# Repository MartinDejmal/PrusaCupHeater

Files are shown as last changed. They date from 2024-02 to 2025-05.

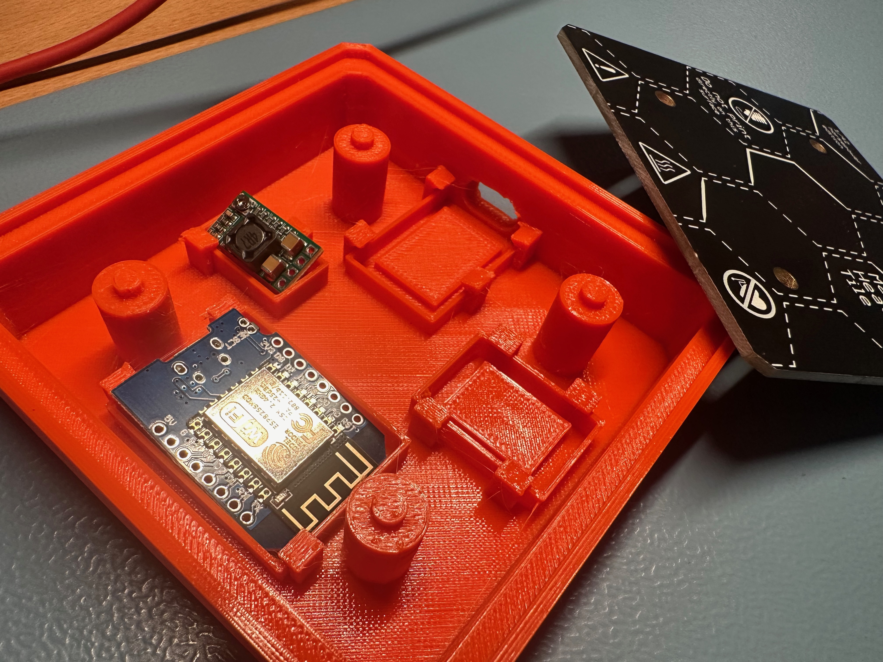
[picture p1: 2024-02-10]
Pictures/IMG_0196.jpeg

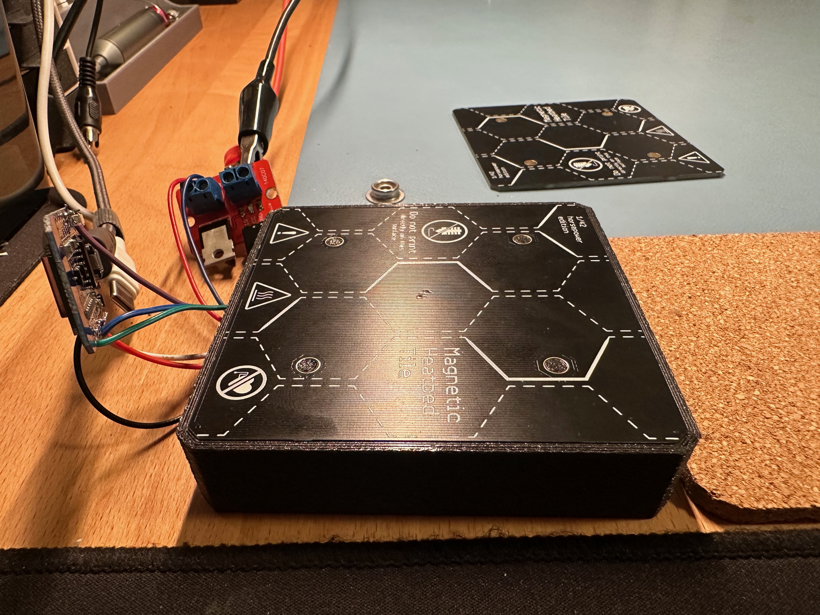
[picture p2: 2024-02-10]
Pictures/IMG_0191.jpeg

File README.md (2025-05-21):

# PrusaCupHeater

PrusaCupHeater is a project aiming to utilize spare / waste heatbedlets (heat bed tiles) from **Prusa XL printer**. 

The ultimate objective was to build a cup heater that can be powered from USB-C PD power supply and connected to Home Assistant. 

Original idea and design by [Martin Velisek](https://x.com/martin_velisek) & [Martin Dejmal](https://x.com/KutilDomaci).

## Required parts

* Prusa XL Heat Bed Tile (obviously)
* Wemos D1 Mini ESP8266 module (or similar)
* DS18B20 temperature sensor (or any alternative)
* power MOSFET/PWM breakout board
* USB-C PD Trigger with 20V out support
* DC-DC step-down converter (at least 24V input, 5V output)
* optional: 3 LED strip WS2812B
* 3D Printed box

### Purchase links

| Component/Module | CZ | International |
| --- | --- | --- |
| Prusa XL Heatbed tile | [prusa3d.com](https://www.prusa3d.com/cs/produkt/heatbed-tile/) ||
| Wemos D1 Mini | [laskakit.cz](https://www.laskakit.cz/wemos-d1-mini-esp8266-wifi-modul/), [pajenicko.cz](https://pajenicko.cz/wemos-d1-mini-wifi-esp8266-esp-12f-microusb) | [Aliexpress](https://www.aliexpress.com/item/1005006473868001.html) |
| DS18B20 temp sensor | [laskakit.cz](https://www.laskakit.cz/dallas-digitalni-cidlo-teploty-ds18b20--to-92/), [pajenicko.cz](https://pajenicko.cz/digitalni-cidlo-teploty-dallas-ds18b20) | [Aliexpress](https://www.aliexpress.com/item/1005006105455874.html) |
| MOSFET module | [laskakit.cz](https://www.laskakit.cz/pwm-mosfet-modul-d4184--40vdc-50a/)|[Aliexpress](https://www.aliexpress.com/item/1005004768394186.html) |
| USB-C PD trigger | [laskakit.cz](https://www.laskakit.cz/laskakit-usb-c-pd-ch224k-prepinac-napajeciho-napeti/) | |
| DC-DC Step-down converter | [laskakit.cz](https://www.laskakit.cz/mikro-step-down-menic--nastavitelny/), [pajenicko.cz](https://pajenicko.cz/miniaturni-menic-napeti-step-down-4-dot-5v-24v-na-0-dot-8v17v-az-3a) | [Aliexpress](https://www.aliexpress.com/item/32807048132.html) |
| WS2812 LED strip (60 LED/m; 3 LEDs total) | [laskakit.cz](https://www.laskakit.cz/led-pasek-neopixel-ws2812b-60led-m-ip65-5m-cerny/), [pajenicko.cz](https://pajenicko.cz/inteligentni-rgb-led-pasek-1m-ws2812-neopixel-60led-m-18w-m) | |

## Assembly instructions
- wire up the modules following way:
  - **DS18B20** to pin D7 on **Wemos D1**, glue the sensor to the bottom of the heat bed tile  
  - power MOSFET module to pin D1 on **Wemos D1**
  - (optional) **WS2812** to pin D6 on **Wemos D1** 
- jumper the USB-C trigger to output 20V
  - wire 20V out from the PD trigger into the MOSFET switching part
  - connect power pins from MOSFET trigger into the heat bed tile

## Firmware instructions
- flash `tasmota-sensors` into the **Wemos D1**, you can use [Tasmota Web Installer](https://tasmota.github.io/install/)
- apply following template:
  - without **WS2812** `{"NAME":"PrusaCupHeater","GPIO":[0,0,0,0,0,224,0,0,0,1312,0,0,0,0],"FLAG":0,"BASE":18}`
  - with **WS2812** `{"NAME":"PrusaCupHeater","GPIO":[0,0,0,0,0,224,0,0,1376,1312,0,0,0,0],"FLAG":0,"BASE":18}`

## Home Assistant configuration
Prerequisite: Tasmota integration working with MQTT server
- if you want to control the Cup Heater via Home Assistant, you need to define a thermostat
- open your configuration.yaml and add following:
```
  climate:
    - platform: generic_thermostat
      unique_id: prusa_cup_heate
      name: PrusaCupHeater
      heater: switch.tasmota_2
      target_sensor: sensor.tasmota_ds18b20_temperature
      min_temp: 40
      max_temp: 120
```
Replace `switch.tasmota_2` and `sensor.tasmota_ds18b20_temperature` by relevant heater switch and temperature sensors entities in your setup. 
- change **Logging interval** on your Tasmota to lowest possible value (10s) - **Configuration -> Configure Logging -> Telemetry Period**

## Standalone operation configuration
It is possible to enable simple heating control using Tasmota Rules. To do this, open **Tasmota Console** and create two rules by entering following commands:
  - `Rule1 ON Tele-DS18B20#Temperature<55 DO Power1 1 ENDON`
  - `Rule2 ON Tele-DS18B20#Temperature>65 DO Power1 0 ENDON`
- enable the rules using following commands:
  - `Rule1 1`
  - `Rule2 1`
- if you have **WS2812** add third rule to light it up when heating is active:
  - `Rule3 ON Power1#State=1 DO Power2 1 ENDON ON Power1#State=0 DO Power2 0 ENDON`
  - enable the rule: `Rule3 1`
- to make it update correctly change **Logging interval** on your Tasmota to lowest possible value (10s) - **Configuration -> Configure Logging -> Telemetry Period**

You can adjust target temperature and temperature hysteresis limits as per your requirements. The setup described above has target 60°C while allowing +/-5°C hysteresis.
Note: berry scripting is not supported on ESP8266 devices.

## To do list
✅ include WS2812b LED strip control

✅ add berry script for autonomous operation

🔲 add pictures to the description

🔲 add wiring diagram

🔲 add touch sensor to control operation

🔲 add 128x32 OLED display with temperature and status reading

🔲 add cup presence detection

🔲 leverage internal thermistor on the heatbed tile instead of DS18B20

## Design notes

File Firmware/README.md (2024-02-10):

Firmware information
- best way is to flash latest Tasmota-sensors release using web installer: https://tasmota.github.io/install/

- If not available or possible for some reason, use provided tasmota-sensors.bin (Release 2024-02-09.r.e6515883f0ee5451931b6280ff847b117de5a231 suitable for Wemos D1 Mini with ESP8266)

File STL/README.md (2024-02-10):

3D Model files
- PrusaCupHeater_v1.stl - print it in ASA, ABS or any other higher-temperature-resistant material.

Available also on printables: https://www.printables.com/model/757473-prusa-cup-heater

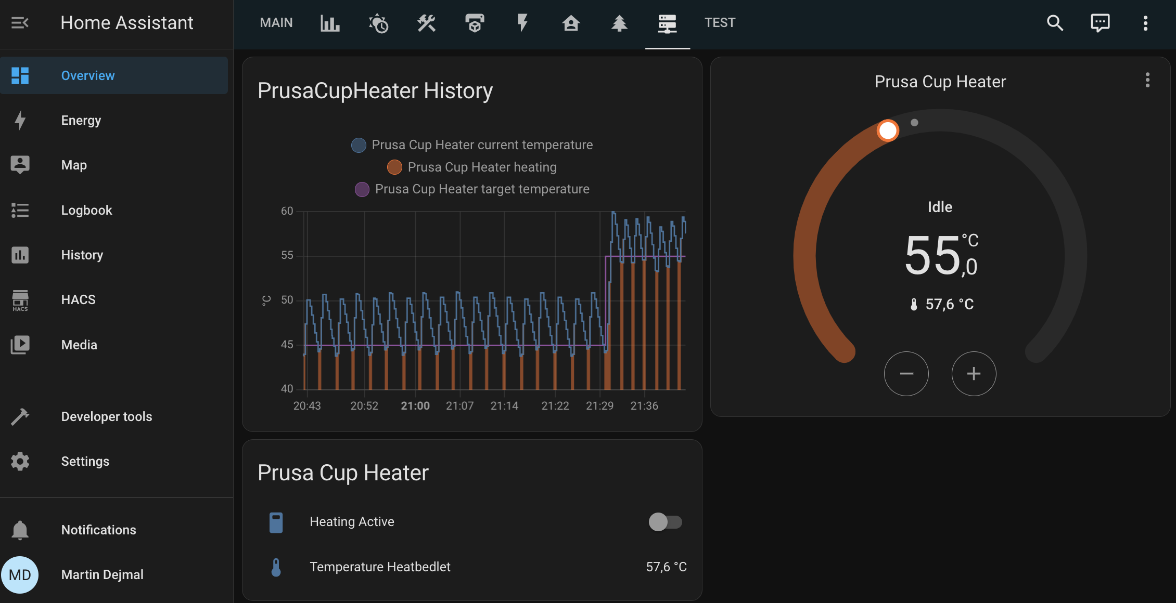
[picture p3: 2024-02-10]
Pictures/HomeAssistant_PrusaCupHeater.png

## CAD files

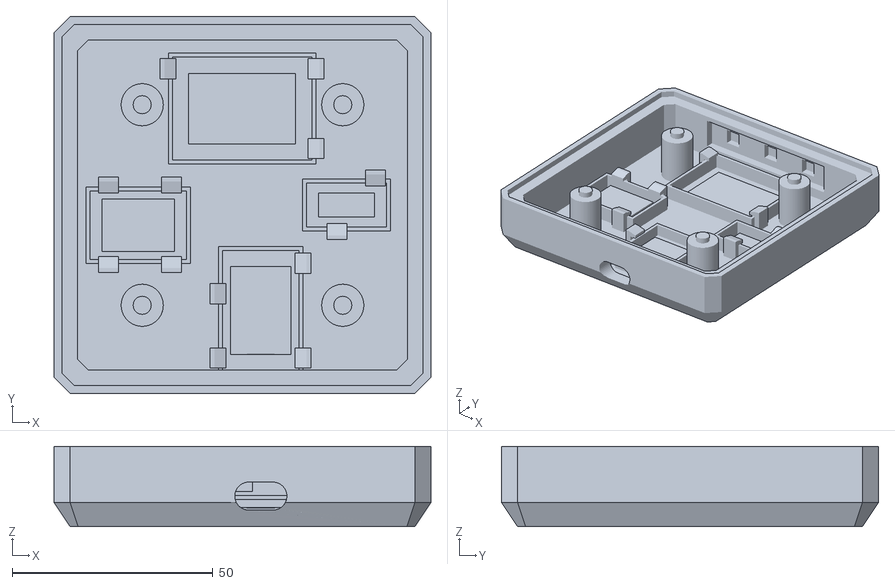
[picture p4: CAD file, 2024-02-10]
STL/PrusaCupHeater.stl
94.0 x 94.0 x 20.0

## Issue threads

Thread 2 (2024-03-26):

Schematic diagram

MartinDejmal, 2024-03-26:
Hello, would it be possible to add schema?

_Originally posted by @Relixtay in https://github.com/MartinDejmal/PrusaCupHeater/issues/1#issuecomment-2020721168_

Keegsy, 2025-09-07:
I'd also appreciate an electrical schematic diagram

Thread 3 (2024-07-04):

use internal thermistor instead external

sl1pkn07, 2024-07-04:
Hi

the heatbed tiles have an internal thermistor called TH1 routed to pins in the connector

is possible use it instead the external ones?

greetings

MartinDejmal, 2024-07-04:
Hi, since I have all samples just bare PCBs, the thermistors are not populated.
It should be quite easy to implement though, just wire it to some analog pins of the ESP board and you are good to go.

sl1pkn07, 2024-07-04:
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
